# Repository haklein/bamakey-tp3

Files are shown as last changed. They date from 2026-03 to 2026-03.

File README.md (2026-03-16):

# bamakey-tp3
BaMaTech BaMaKey TP-iii clone. As Markus Baseler is < SK >, this is an attempt to reproduce the 3d files and BOM for his amazing TP-iii morse paddle.

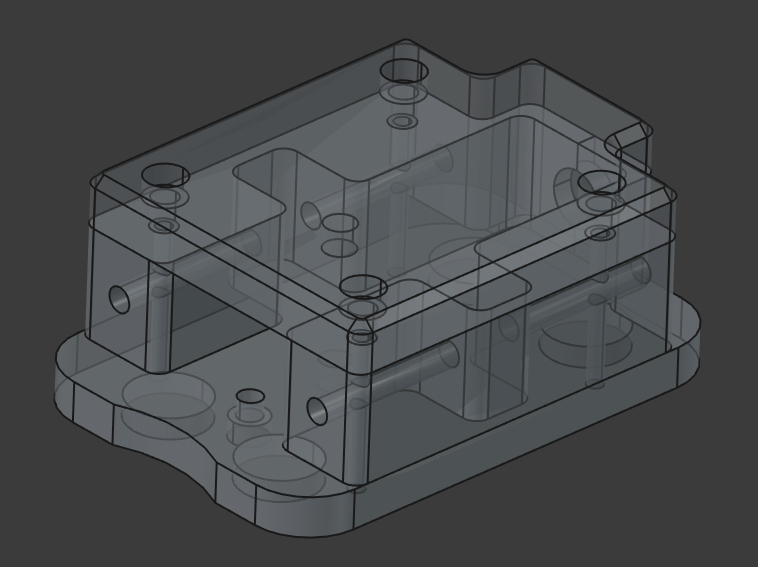
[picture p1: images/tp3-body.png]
TP-iii body


# experimental BOM

- 1x ISO 8734 Dowel pin 3x16mm m6 
- 4x M2 screws for acrylic top cover
- 4x M3 grub screws to fixate the M5 retention/magnet grub screws
- 2x Button head screws unslotted for contact points on lever, got these but they're a tad to big: https://knupfer.info/shop/index.php/nieten-nietenschrauben/nietkopf-schrauben.html
- 4x M5x0,5x12 fine thread grub screws for magnets and retention, e.g. https://de.aliexpress.com/item/1005008239921011.html
- 3x2mm round magnets (used FPMYB)
- grub screw dog point plastic fine thread m5x0,5 would be good but didn't find any

- Isolating ball bearings: SS-HC-693-2RS-CN-ZV2-P6-GS Hybrid (Keramik, Edelstahl) Präzisions Miniatur Kugellager SS HC 693 2RS CN ZV2 P6 GS 3x8x4 mm

# cnc parts
First test run (paddles not yet in final shape):
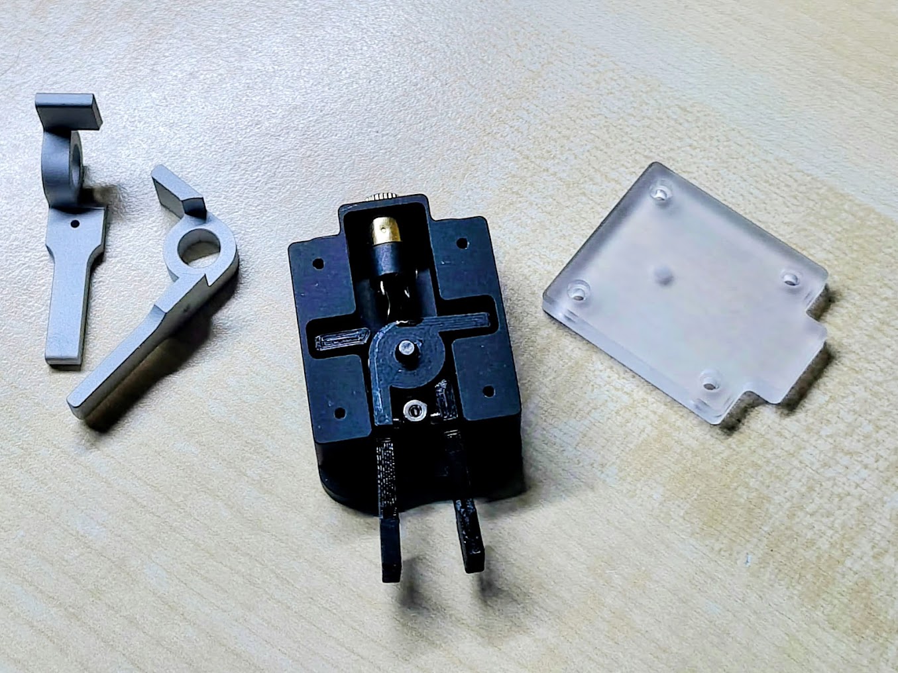
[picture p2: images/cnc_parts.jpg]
cnc-parts


Fitting test vice versa with original parts:
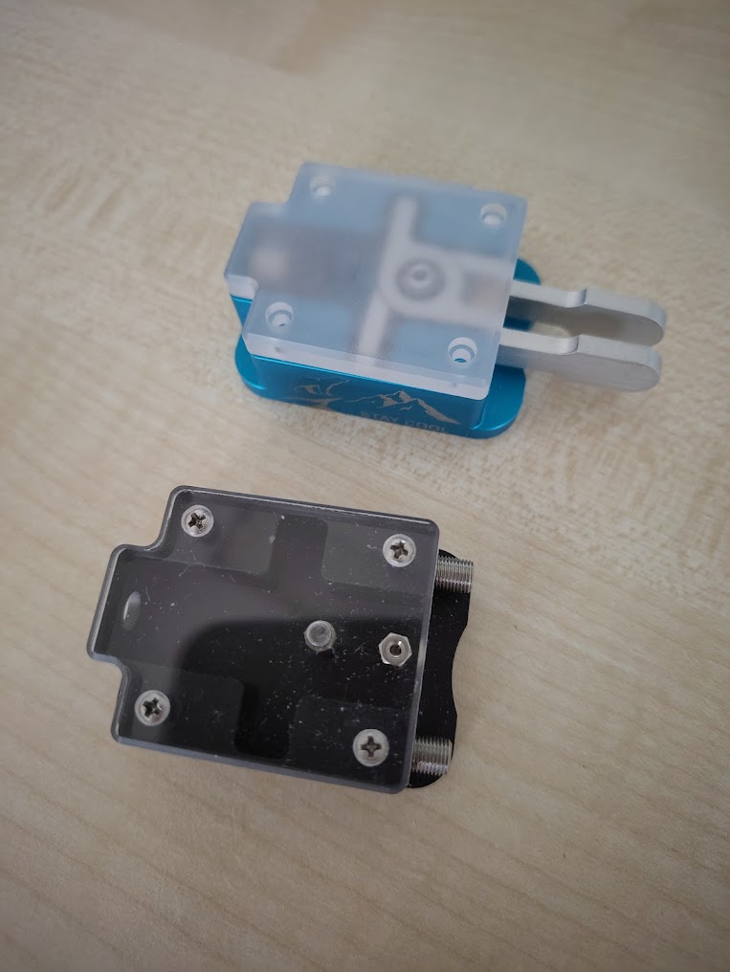
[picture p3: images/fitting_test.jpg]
fitting-test


Fitting of all threads:
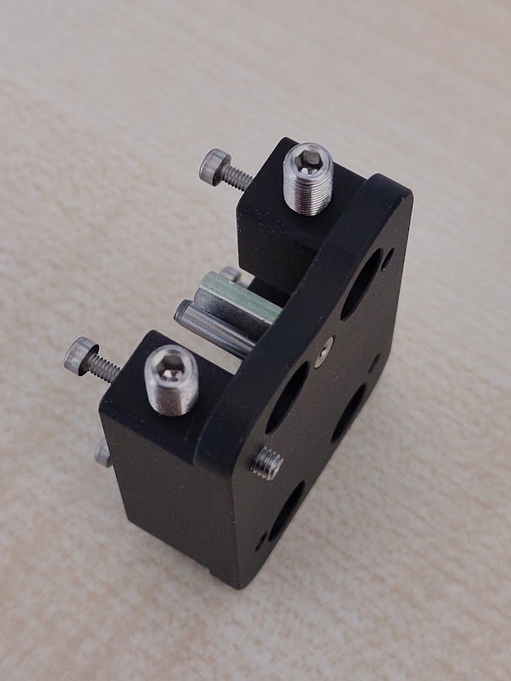
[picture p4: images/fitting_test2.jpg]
fitting-test2


# caveats
## bearings
The original key has a plastic sleeve around the bearing for galvanic isolation. A printed one (PETG) is too sloppy, the paddles have too much flex. So the best idea so far is to use isolating bearings. CNC shop didn't guarantee tolerances for the bearing seat, so that's another topic.

## contact block
Very tight spacing:

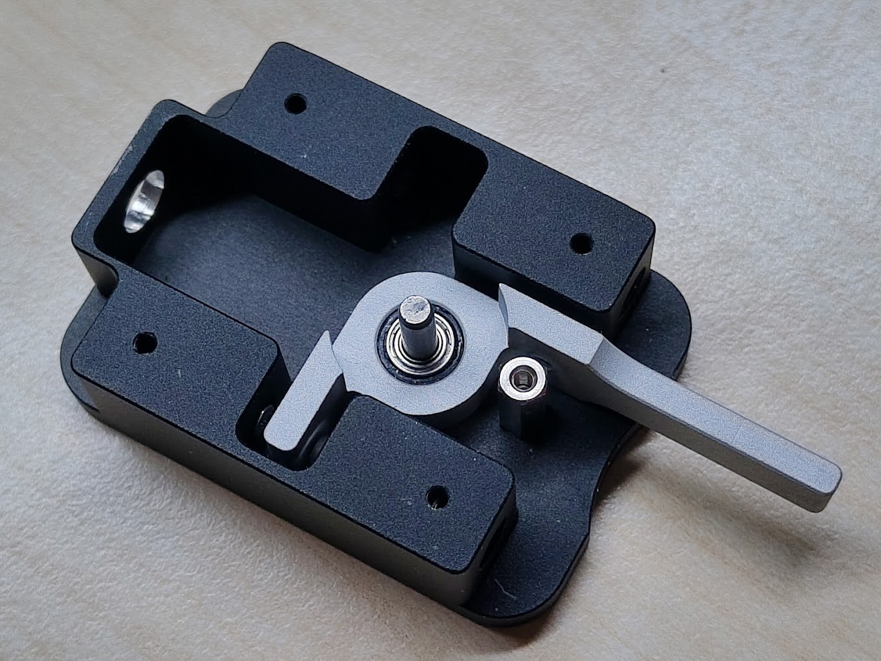
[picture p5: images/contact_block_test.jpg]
contact_block_test

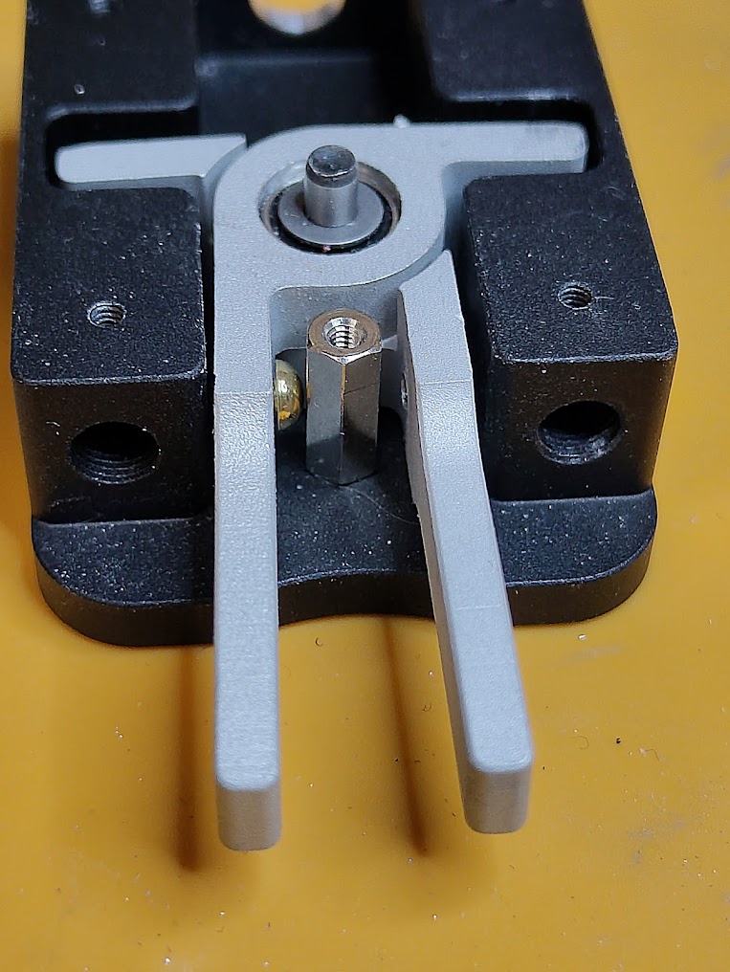
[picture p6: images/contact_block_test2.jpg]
contact_block_test2


## magnet tip grub screw
Didn't find any M5 fine threaded grub screws with magnetic tip. Self-made prototype:

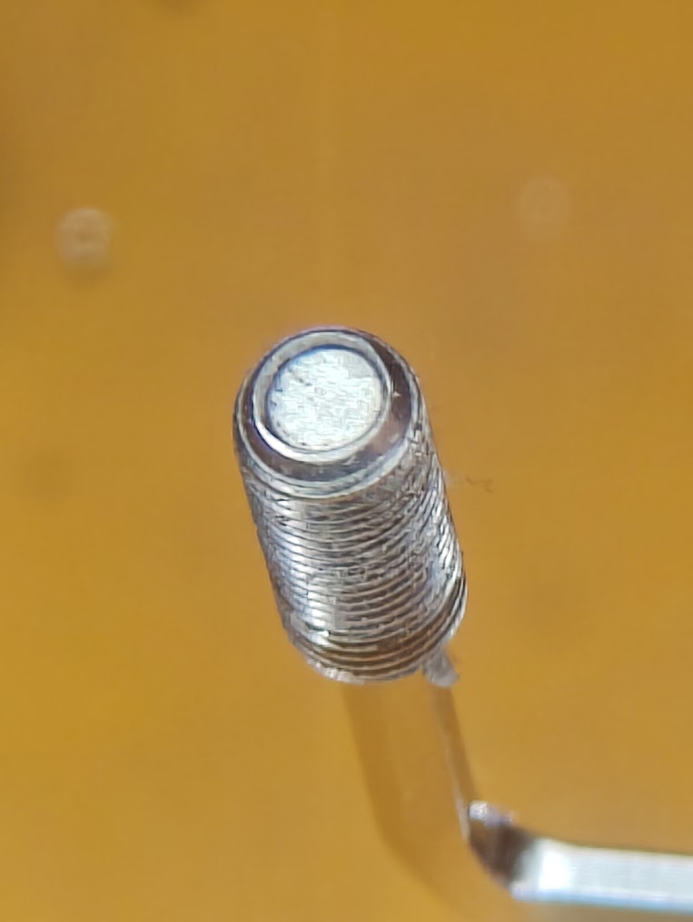
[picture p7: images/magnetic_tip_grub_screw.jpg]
magnetic_tip_grub_screw


Variant with glued on magnet:

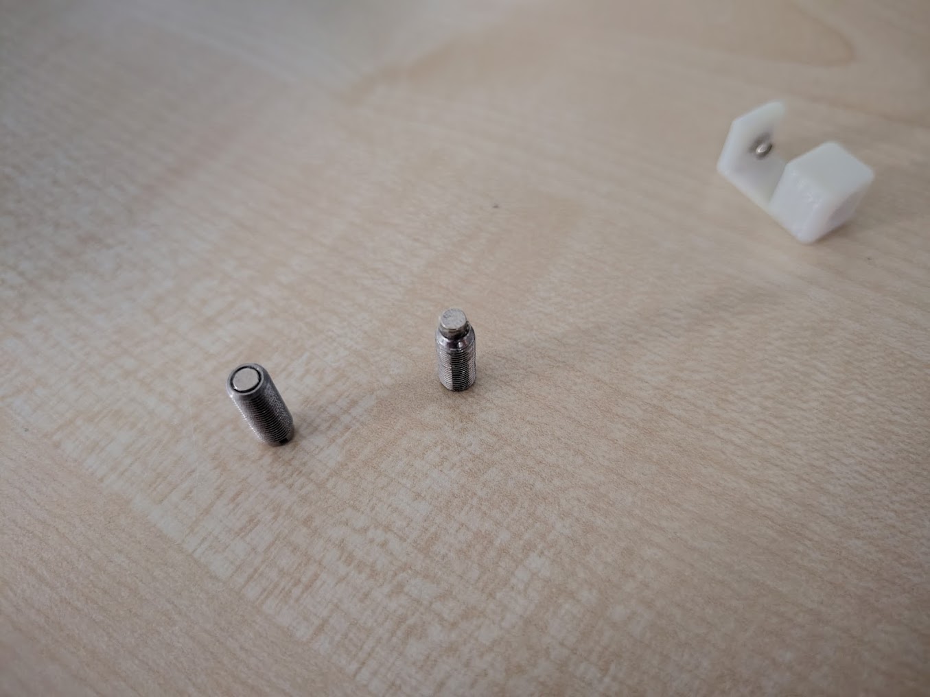
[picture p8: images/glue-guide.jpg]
glued_tip


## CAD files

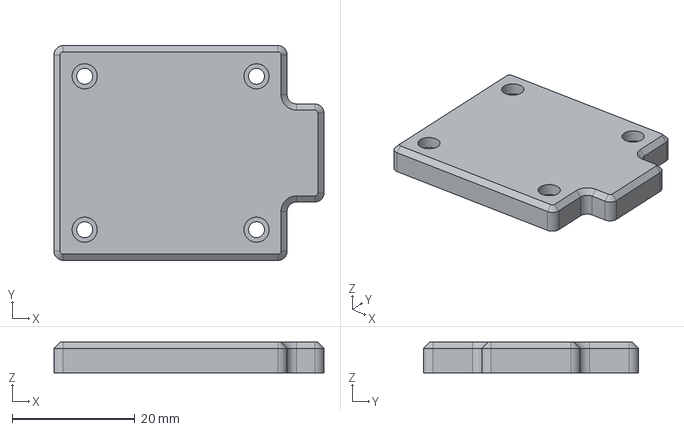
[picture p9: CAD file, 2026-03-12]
cad/BaMaKey-TPIII-TopHole004.step
44.0 x 35.0 x 5.00 mm

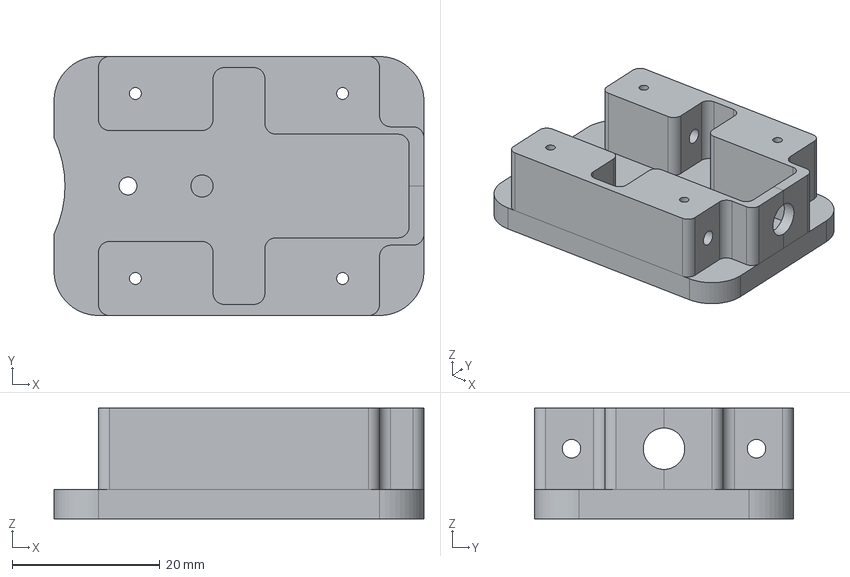
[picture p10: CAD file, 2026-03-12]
cad/BaMaKey-TPIII-Body.step
50.0 x 35.0 x 15.0 mm

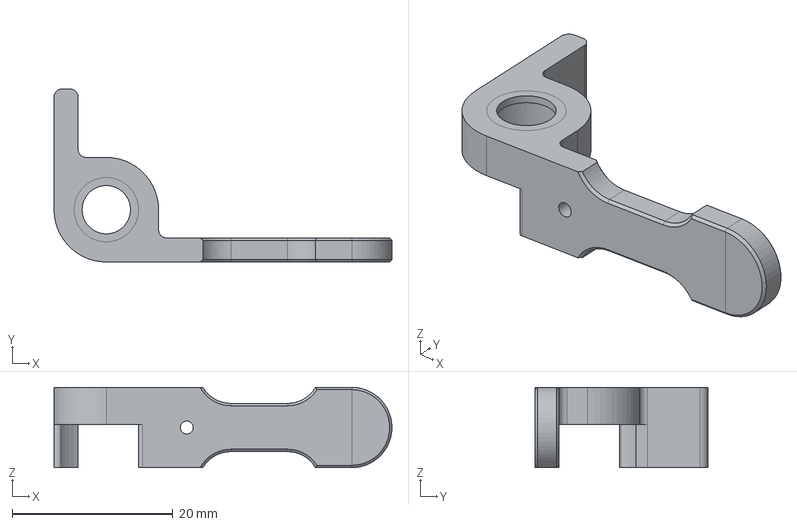
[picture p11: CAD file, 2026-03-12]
cad/BaMaKey-TPIII_paddle_v5-Paddle.step
42.0 x 21.5 x 10.0 mm

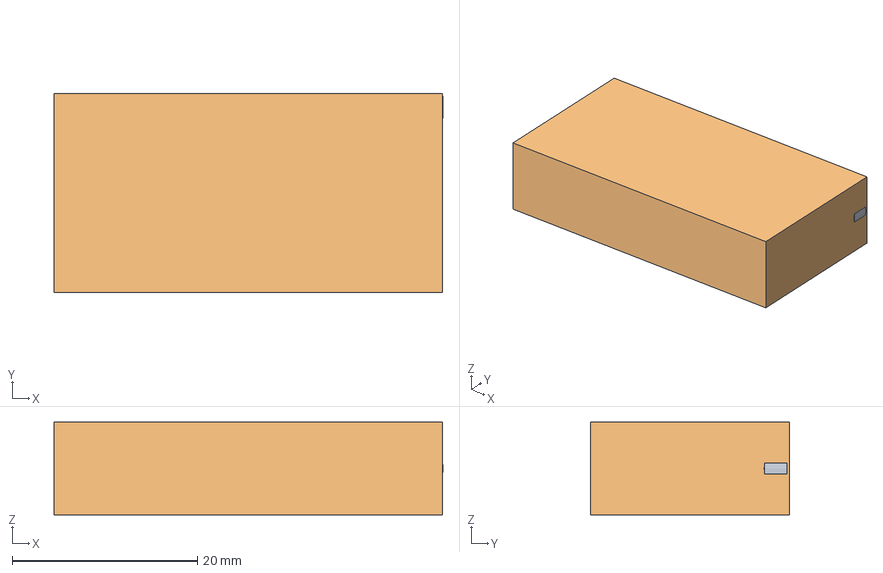
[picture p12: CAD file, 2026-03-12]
cad/BaMaKey-TPIII_paddle_v5.FCStd
42.0 x 21.5 x 10.0 mm
Model-Paddle
Stock

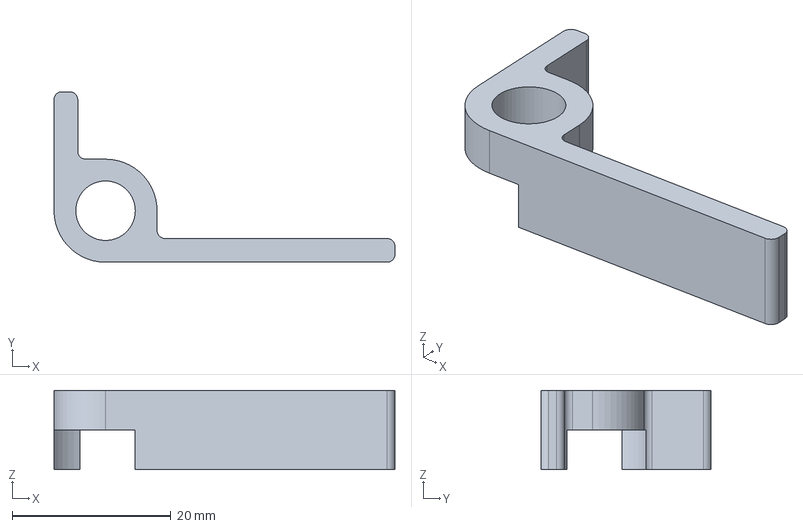
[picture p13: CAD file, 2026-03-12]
cad/BaMaKey-TPIII.FCStd
43.0 x 21.5 x 10.0 mm

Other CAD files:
stl/BaMaKey-TPIII-Top.stl
stl/BaMaKey-TPIII-Body.stl
stl/BaMaKey-TPIII_paddle_v5-Paddle.stl

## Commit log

2026-03-12 Update README with BOM details
    Added Bill of Materials (BOM) for the project.
2026-03-12 Format BOM section in README.md
2026-03-12 add cad files
    [BaMaKey-TPIII-Body.step, BaMaKey-TPIII-TopHole004.step, BaMaKey-TPIII.FCStd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]
2026-03-12 add stl files
    [BaMaKey-TPIII-Body.stl, BaMaKey-TPIII-Top.stl, BaMaKey-TPIII_paddle_v5-Paddle.stl]
2026-03-12 Update README with experimental BOM and caveats
    Added sections for experimental BOM, CNC parts, caveats, and images.
